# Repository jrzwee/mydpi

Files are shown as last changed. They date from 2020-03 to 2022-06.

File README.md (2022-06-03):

# mydpi
OpenSource debugger and programmer for ATmega and ATtiny microcontrollers from Microchip.

<p align="center">
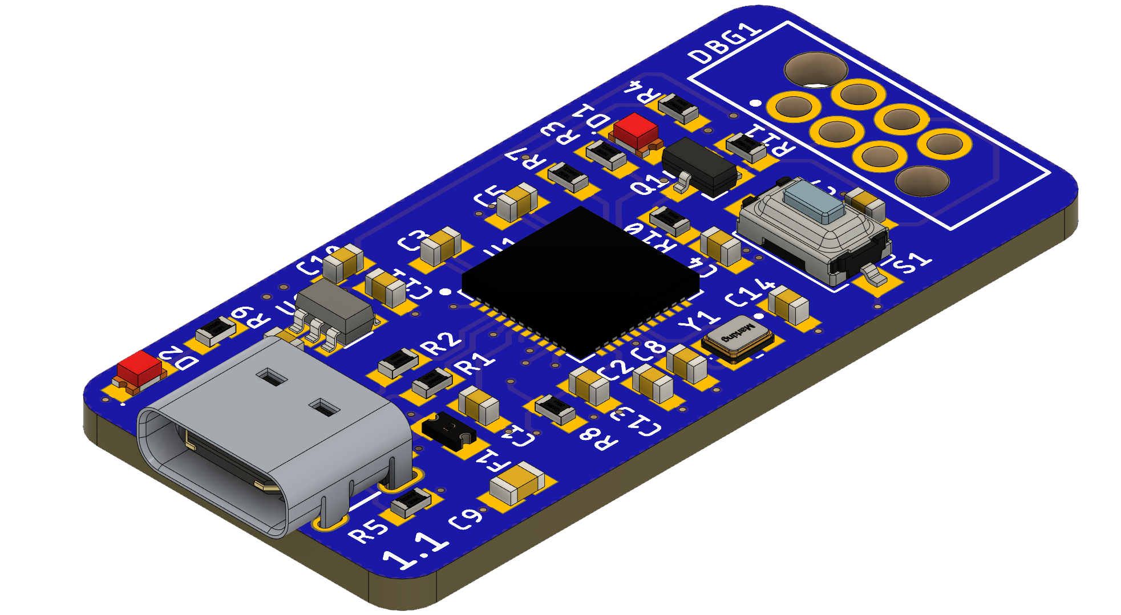
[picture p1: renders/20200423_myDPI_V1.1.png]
  
</p>

## Usage
+ Connect the myDPI to your computer, it should be recognised automatically. 
+ In Atmel Studio choose the myDPI debugger.
+ Set brakepoints, start debugging.

The connection to the device is realised with a Wurth Electronics [REDFIT](https://www.we-online.com/web/en/electronic_components/produkte_pb/produktinnovationen/redfit.php)
connector.

## Compatible Microcontrollers
+ ATtiny20x/40x/80x/160x
+ ATtiny21x/41x/81x/161x/321x
+ ATmega80x/160x/320x/480x

## Manufacture PCB
Click the logo to preview the order "**Push to Aisler**":

[](https://aisler.net/p/new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)

If you like this project, feel free to support me 😇

<a href="https://www.buymeacoffee.com/zaan" target="_blank">Buy Me A Coffee</a>

## License
[CERN-OHL-S](https://ohwr.org/cern_ohl_s_v2.pdf)

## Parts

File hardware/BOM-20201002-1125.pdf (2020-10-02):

Model | myDPI
Version | 1.0
BOM Revision | A
Initials | AZ
Date | 2020-10-02
Description | Qty | Parts | Value | MPN | MF | Info
Surface Mount Capacitor | 6 | C2, C3, C4, C5, C11, C13 | 100n 0603 50V X7R 5% | CC0603JRX7R9BB104 | Yageo
Surface Mount Resistor | 3 | R3, R4, R9 | 1k 0603 75V 1% | RC0603FR-071KL | Yageo
Surface Mount Capacitor | 3 | C1, C10, C12 | 1u 0603 25V X5R 10% | CC0603KRX5R8BB105 | Yageo
Surface Mount Resistor | 2 | R7, R8 | 100k 0603 75V 1% | RC0603FR-07100KL | Yageo
Surface Mount Capacitor | 2 | C8, C14 | 12p 0603 50V C0G/NPO 5% | CC0603JRNPO9BN120 | Yageo
Surface Mount Resistor | 2 | R1, R2 | 22R 0603 75V 1% | RC0603FR-0722RL | Yageo
Surface Mount Resistor | 2 | R10, R11 | 4.7k 0603 75V 1% | RC0603FR-074K7L | Yageo
Surface Mount Resistor | 2 | R5, R6 | 5.1k 0603 75V 1% | RC0603FR-075K1L | Yageo
Surface Mount LED | 2 | D1, D2 | 0805 | LTST-C171KSKT | Lite-On
USB Type C Female | 1 | J1 | USB-C 16P | C167321 | Jing Extension
Surface Mount Capacitor | 1 | C7 | 1n 0603 50V C0G/NPO 5% | CC0603JRNPO9BN102 | Yageo
Surface Mount Capacitor | 1 | C9 | 22u 0805 25V X5R 20% | GRM21BR61E226ME44L Murata
Crystal | 1 | Y1 | 2520 | 830069392 | Wurth Electronics
N-CHANNEL MOSFET | 1 | Q1 | SOT-23 | DMN3404L-7 | Diodes Incorporated
Microcontroller | 1 | U1 | QFN-44 | ATMEGA32U4-MU | Atmel
PTC Fuse | 1 | F1 | 2012 | MF-PSMF035X-2 | Bourns
Low Dropout Regulator | 1 | U2 | SOT-23-5 | RT9193-33GB | Richtek
Tactile Button | 1 | S1 | 6.1X3.6X2.5 | K2-1107ST-A4SW-06 | Korean Hroparts Elec

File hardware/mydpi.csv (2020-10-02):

Qty | Value | Device | Package | Parts | Description | DESCRIPTION | DIELECTRIC | MF | MPN | PACKAGE | PACKAGE-IN | POPULARITY | POWER | TOLERANCE | VALUE | VOLTAGE
1 |  | SJ2W | SJ_2 | SJ1 | SMD solder JUMPER |  |  |  |  |  |  | 7
1 |  | USB_C2-LAYER | USB-C-16P | J1 | USB Type C 16 Pin Connector | USB Type C Female |  | Jing Extension | C167321 | USB-C 16P
2 | 100k | 100KOHM-0603-1/10W-1% | R0603 | R7, R8 | 100kΩ resistor | Surface Mount Resistor |  | Yageo | RC0603FR-07100KL | 1608 | 0603 |  | 0.1W | 1% | 100k | 75V
6 | 100n | 100NF-0603-50V-5% | C0603 | C2, C3, C4, C5, C11, C13 | 100nF capacitor | Surface Mount Capacitor | X7R | Yageo | CC0603JRX7R9BB104 | 1606 | 0603 |  |  | 5% | 100n | 50V
2 | 12p | 12PF-0603-50V-5% | C0603 | C8, C14 | 12pF capacitor | Surface Mount Capacitor | C0G/NPO | Yageo | CC0603JRNPO9BN120 | 1606 | 0603 |  |  | 5% | 12p | 50V
3 | 1k | 1KOHM-0603-1/10W-1% | R0603 | R3, R4, R9 | 1kΩ resistor | Surface Mount Resistor |  | Yageo | RC0603FR-071KL | 1608 | 0603 |  | 0.1W | 1% | 1k | 75V
1 | 1n | 1NF-0603-50V-5% | C0603 | C7 | 1nF capacitor | Surface Mount Capacitor | C0G/NPO | Yageo | CC0603JRNPO9BN102 | 1608 | 0603 |  |  | 5% | 1n | 50V
3 | 1u | 1UF-0603-25V-10% | C0603 | C1, C10, C12 | 1uF capacitor | Surface Mount Capacitor | X5R | Yageo | CC0603KRX5R8BB105 | 1606 | 0603 |  |  | 10% | 1u | 25V
2 | 22R | 22OHM-0603-1/10W-1% | R0603 | R1, R2 | 22Ω resistor | Surface Mount Resistor |  | Yageo | RC0603FR-0722RL | 1608 | 0603 |  | 0.1W | 1% | 22R | 75V
1 | 22u | 22UF-0805-25V-20% | C0805 | C9 | 22uF capacitor | Surface Mount Capacitor | X5R | Murata | GRM21BR61E226ME44L | 2012 | 0805 |  |  | 20% | 22u | 25V
2 | 4.7k | 4.7KOHM-0603-1/10W-1% | R0603 | R10, R11 | 4.7kΩ resistor | Surface Mount Resistor |  | Yageo | RC0603FR-074K7L | 1608 | 0603 |  | 0.1W | 1% | 4.7k | 75V
2 | 5.1k | 5.1KOHM-0603-1/10W-1% | R0603 | R5, R6 | 5.1kΩ resistor | Surface Mount Resistor |  | Yageo | RC0603FR-075K1L | 1608 | 0603 |  | 0.1W | 1% | 5.1k | 75V
1 | 830069392 | 830069392 | WE-XTAL_CFPX-218 | Y1 | Crystal | Crystal |  | Wurth Electronics | 830069392 | 2520
1 | AVR-ISP-SMD | AVR-ISP-SMD | AVRISP-1.27-SMD | ICSP1
1 | AVR-UPDI-6-SKEDD | AVR-UPDI-6-SKEDD | 490107670612_DEBUGGING | DBG1
1 | DMN3404L | DMN3404L | SOT23 | Q1 | N-CHANNEL MOS FET | N-CHANNEL MOSFET |  | Diodes Incorporated | DMN3404L-7 | SOT-23
2 | LTST-C171KSKT | LTST-C171KSKT | CHIPLED_0805 | D1, D2 | SMD LED | Surface Mount LED |  | Lite-On | LTST-C171KSKT | 2012 | 0805
1 | MEGA32U4-MU | MEGA32U4-MU | TQFN44_7MM | U1 | ATmega32u4 | Microcontroller |  | Atmel | ATMEGA32U4-MU | QFN-44
1 | MF-PSMF035X-2 | MF-PSMF035X-2 | F0805 | F1 | PTC Resetable Fuse | PTC Fuse |  | Bourns | MF-PSMF035X-2 | 2012
1 | RT9193-33GB | RT9193-33GB | SOT23-5 | U2 | LDO Regulator | Low Dropout Regulator |  | Richtek | RT9193-33GB | SOT-23-5
1 | TS-1101-C-W | TS-1101-C-W | SPST-6X3.6 | S1 | Tactile Button | Tactile Button |  | Korean Hroparts Elec | K2-1107ST-A4SW-06 | 6.1X3.6X2.5

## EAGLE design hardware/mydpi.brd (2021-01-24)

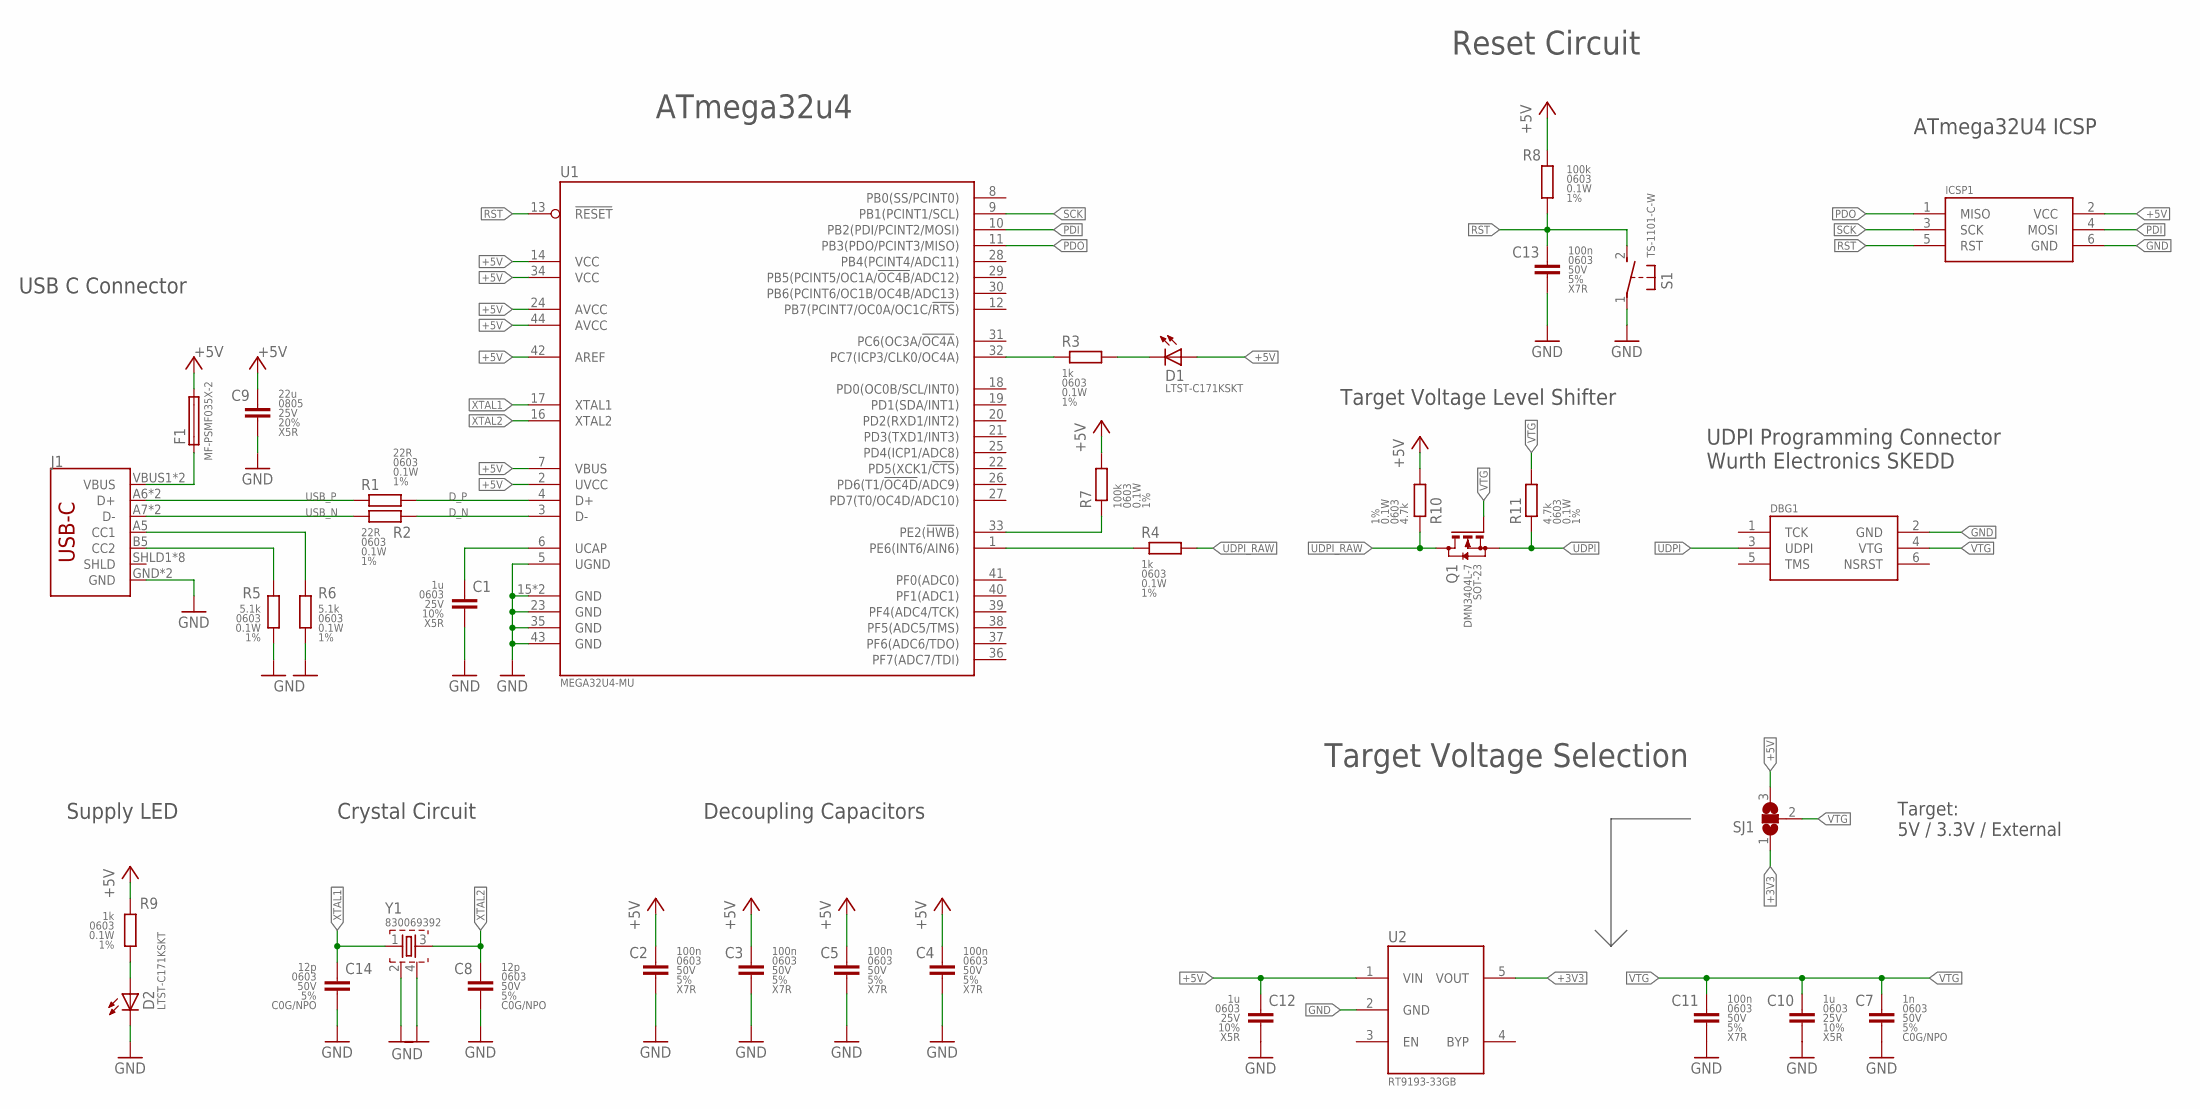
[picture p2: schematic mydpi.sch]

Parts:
C1, C10, C12: 1u; C0603
C2, C3, C4, C5, C11, C13: 100n; C0603
C7: 1n; C0603
C8, C14: 12p; C0603
C9: 22u; C0805
D1, D2: LTST-C171KSKT; CHIPLED_0805
DBG1: AVR-UPDI-6-SKEDD; 490107670612_DEBUGGING
F1: MF-PSMF035X-2; F0805
ICSP1: AVR-ISP-SMD; AVRISP-1.27-SMD
J1: USB_C2-LAYER; USB-C-16P
Q1: DMN3404L; SOT23
R1, R2: 22R; R0603
R3, R4, R9: 1k; R0603
R5, R6: 5.1k; R0603
R7, R8: 100k; R0603
R10, R11: 4.7k; R0603
S1: TS-1101-C-W; SPST-6X3.6
SJ1: SJ2W; SJ_2
U1: MEGA32U4-MU; TQFN44_7MM
U2: RT9193-33GB; SOT23-5
Y1: 830069392; WE-XTAL_CFPX-218

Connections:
+3V3: SJ1.1, U2.5 (VOUT)
+5V: C2.1, C3.1, C4.1, C5.1, C9.1, C12.1, D1.A, F1.2, ICSP1.2 (VCC), R7.2, R8.2, R9.1, R10.2, SJ1.3, U1.2 (UVCC), U1.7 (VBUS), U1.14 (VCC), U1.24 (AVCC), U1.34 (VCC), U1.42 (AREF), U1.44 (AVCC), U2.1 (VIN)
D_N: R2.2, U1.3 (D-)
D_P: R1.2, U1.4 (D+)
GND: C1.2, C2.2, C3.2, C4.2, C5.2, C7.2, C8.2, C9.2, C10.2, C11.2, C12.2, C13.2, C14.2, D2.C, DBG1.2 (GND), ICSP1.6 (GND), J1.GND, J1.GND2 (GND), R5.1, R6.1, S1.1, U1.5 (UGND), U1.15 (GND), U1.23 (GND), U1.35 (GND), U1.43 (GND), U1.EXP (GND), U2.2 (GND), Y1.2, Y1.4
unnamed: R3.1, U1.32 (PC7(ICP3/CLK0/OC4A))
unnamed: D1.C, R3.2
unnamed: J1.B5 (CC2), R5.2
unnamed: J1.A5 (CC1), R6.2
unnamed: R7.1, U1.33 (PE2(!HWB!))
unnamed: C1.1, U1.6 (UCAP)
unnamed: D2.A, R9.2
unnamed: F1.1, J1.VBUS1 (VBUS), J1.VBUS2 (VBUS)
PDI: ICSP1.4 (MOSI), U1.10 (PB2(PDI/PCINT2/MOSI))
PDO: ICSP1.1 (MISO), U1.11 (PB3(PDO/PCINT3/MISO))
PE6: R4.1, U1.1 (PE6(INT6/AIN6))
RST: C13.1, ICSP1.5 (RST), R8.1, S1.2 (S), U1.13 (!RESET!)
SCK: ICSP1.3 (SCK), U1.9 (PB1(PCINT1/SCL))
UDPI: DBG1.3 (UDPI), Q1.2 (S), R11.1
UDPI_RAW: Q1.3 (D), R4.2, R10.1
USB_N: J1.A7 (D-), J1.B7 (D-), R2.1
USB_P: J1.A6 (D+), J1.B6 (D+), R1.1
VTG: C7.1, C10.1, C11.1, DBG1.4 (VTG), Q1.1 (G), R11.2, SJ1.2
XTAL1: C14.1, U1.17 (XTAL1), Y1.1
XTAL2: C8.1, U1.16 (XTAL2), Y1.3

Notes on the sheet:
Target: 5V / 3.3V / External
Target Voltage Selection
ATmega32U4 ICSP
Reset Circuit
UDPI Programming Connector Wurth Electronics SKEDD
Target Voltage Level Shifter
ATmega32u4
Crystal Circuit
Supply LED
Decoupling Capacitors
USB C Connector

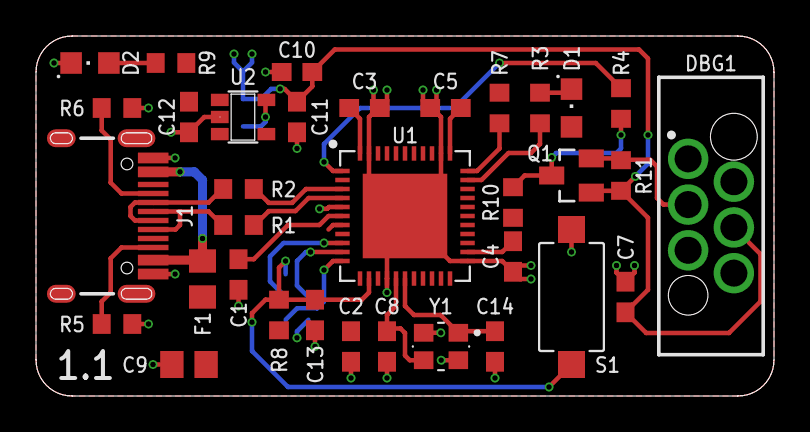
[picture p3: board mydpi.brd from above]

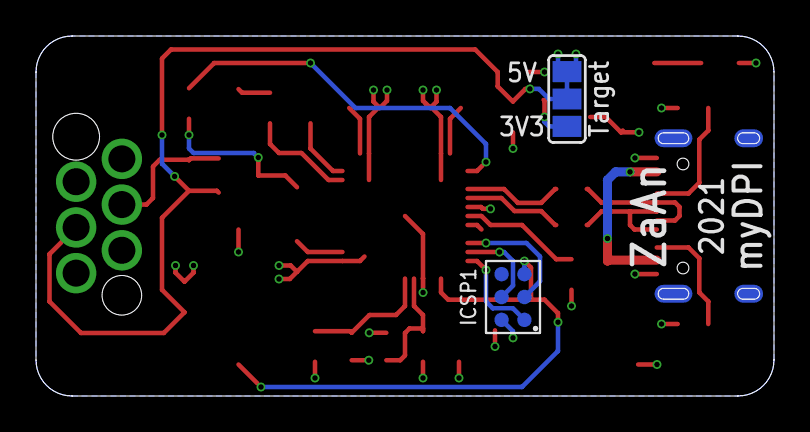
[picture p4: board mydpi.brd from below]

Board: 2 copper layers, 41.0 x 20.0 mm, 36 parts (2 on the bottom side), 25 nets.

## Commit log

2019-11-12 Schematic and board files generated
    [mydpi.brd, mydpi.sch]
2019-11-12 Added supply voltage
    [mydpi.brd, mydpi.sch]
2020-01-26 CC resistors added
    [mydpi.brd, mydpi.sch]
2020-01-26 Placement LDO, Caps
    [mydpi.brd, mydpi.sch]
2020-01-26 Crystal Added
    [mydpi.brd, mydpi.sch]
2020-01-28 Added Reset Switch
    [mydpi.brd, mydpi.sch]
2020-02-02 Button and Fuse added
    [mydpi.brd, mydpi.sch]
2020-02-07 LDO added
    [mydpi.brd, mydpi.sch]
2020-02-07 Minor placement change
    [mydpi.brd]
2020-02-07 Minor changes placement
    [mydpi.brd, mydpi.sch]
2020-02-07 Bugfixes in used libraries
    [mydpi.brd, mydpi.sch]
2020-02-12 Updated Libraries
    [mydpi.brd, mydpi.sch]
2020-03-08 Finished level shifter
    [PnP_mydpi_back.csv, PnP_mydpi_front.csv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]
2020-03-11 Added pullup resistors for level shifting
    [PnP_mydpi_back.csv, PnP_mydpi_front.csv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]
2020-03-17 Routing Pullup Resistors
    [mydpi.brd]
2020-03-25 Changed silkscreen revision number
    [mydpi.brd]
2020-04-23 Restructure folders and added renders of PCB
    [mydpi.brd, mydpi.sch]
2020-10-02 Corrected Vias to 0.3mm, Generated BOM
    [mydpi.brd, mydpi.csv]
2021-01-24 Silkscreen size shrink to 0.81
    [mydpi.brd, mydpi.sch]
